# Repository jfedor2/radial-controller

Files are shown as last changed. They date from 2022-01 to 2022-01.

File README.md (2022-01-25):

# DIY Surface Dial

This repository contains 3D-printable design files and code that can be used to make a Surface Dial compatible USB radial controller.

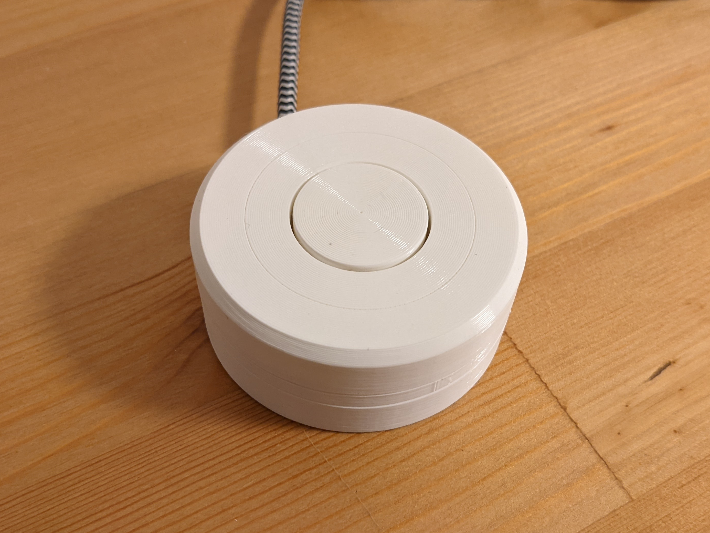
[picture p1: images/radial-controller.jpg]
Radial controller photo


The controller doesn't have all the features of the real Surface Dial. It's not wireless, it's not nearly as precise, it doesn't have haptic feedback and it doesn't have the on-screen positioning magic. But it should work in all applications compatible with the Surface Dial with no additional software.

It uses the following components:

* [Adafruit QT Py RP2040](https://www.adafruit.com/product/4900) (you can use any other board that will fit inside the case, but the code is for the RP2040)
* 2x [SS49E Hall effect sensors](https://sps.honeywell.com/us/en/products/sensing-and-iot/sensors/magnetic-sensors/linear-and-angle-sensor-ics/ss39et-ss49e-ss59et-linear-sensor-ics) (TO-92 package)
* 48x 2x2mm neodymium cylinder magnets (axially magnetized)
* Kailh low profile (choc v1) mechanical keyboard switch
* 30x42x7mm bearing (6806 ZZ)
* 2x M3x4 flat head screws
* a USB cable
* some hookup wire

The bearing and the magnets are press-fit into the case, but depending on your particular printer you might want to use glue. The Hall effect sensors should be oriented "face-up" and will definitely need some glue to stay in place.

The sensors' + and - leads are connected to 3.3V and GND, respectively, and their output leads are connected to pins A2 and A3. The keyboard switch is connected to pin A1 (the other contact to GND).

The magnets should be installed with alternating polarity (the outside-facing pole should be N-S-N-S... etc.).

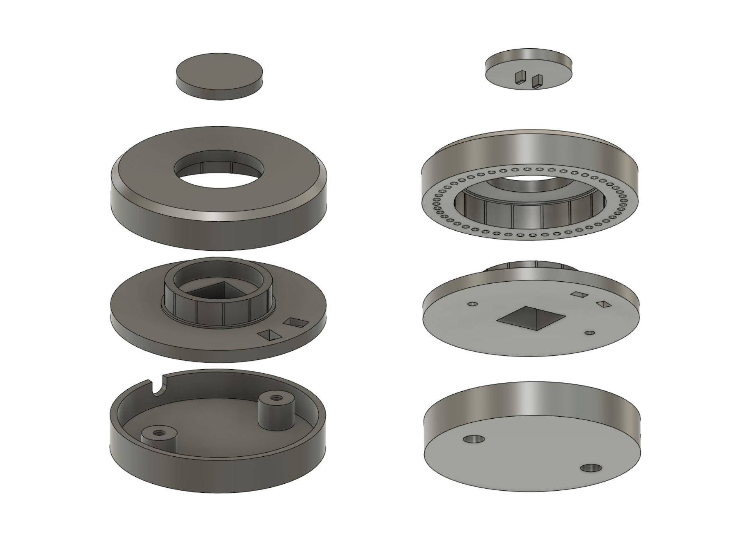
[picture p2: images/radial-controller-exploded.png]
Radial controller exploded view


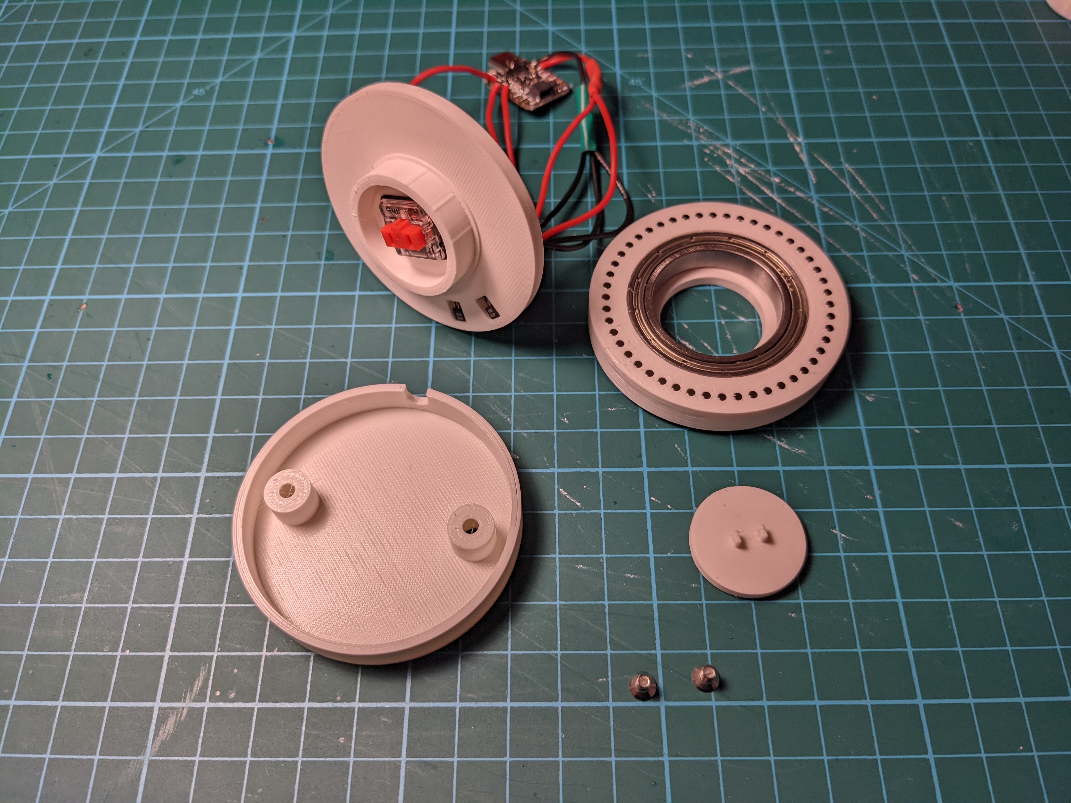
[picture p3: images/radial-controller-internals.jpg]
Radial controller internals


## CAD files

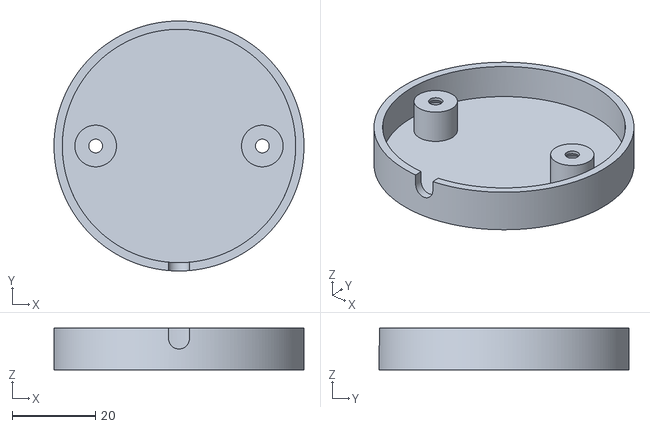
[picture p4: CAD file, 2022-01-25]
3d-models/RadialController-Bottom.stl
60.0 x 60.0 x 10.0

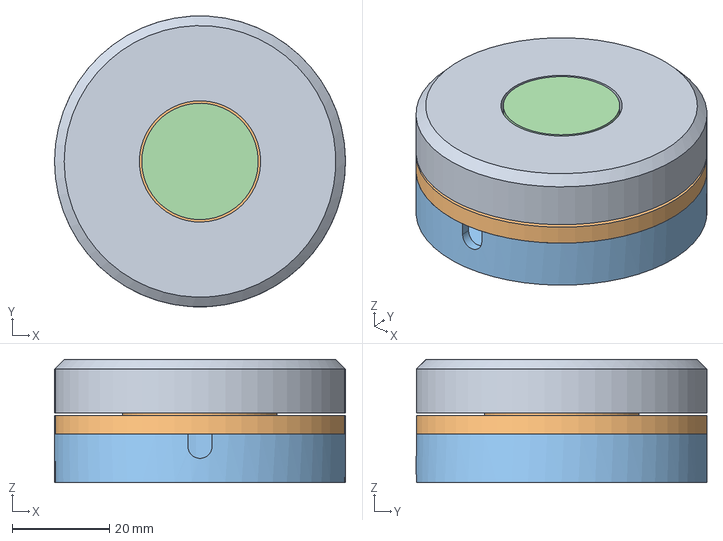
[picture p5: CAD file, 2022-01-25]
3d-models/RadialController.step
60.0 x 60.0 x 25.4 mm

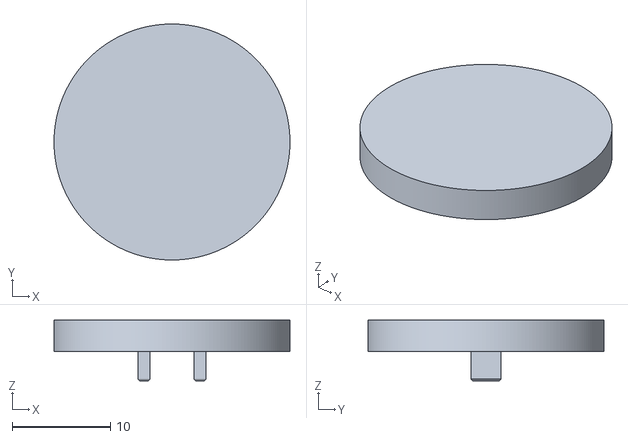
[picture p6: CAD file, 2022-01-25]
3d-models/RadialController-Button.stl
24.0 x 24.0 x 6.20

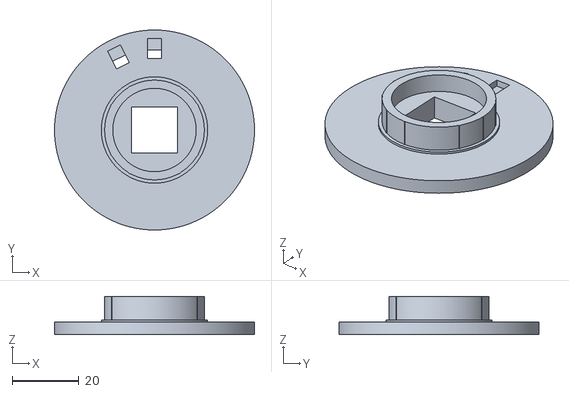
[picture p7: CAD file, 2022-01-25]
3d-models/RadialController-Mid.stl
60.0 x 60.0 x 11.4

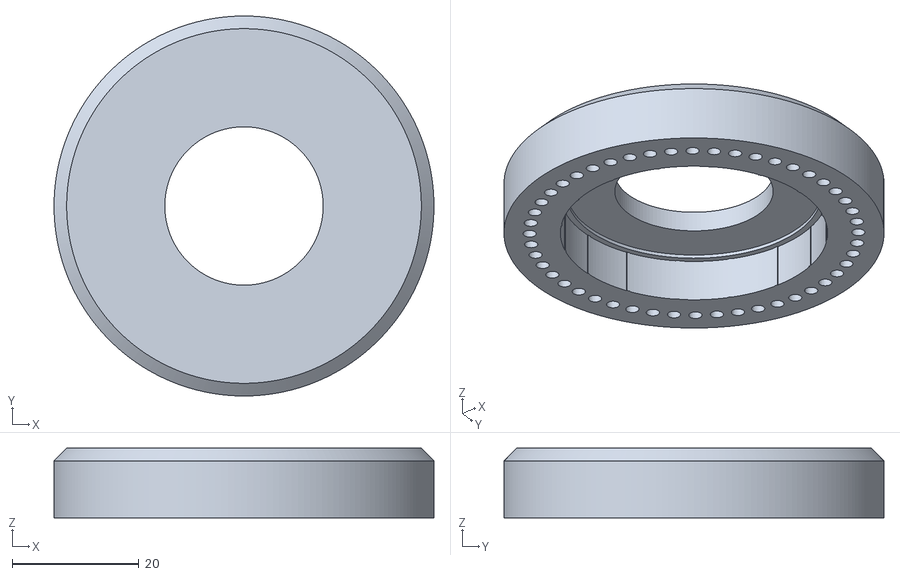
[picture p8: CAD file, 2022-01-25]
3d-models/RadialController-Top.stl
60.0 x 60.0 x 11.0

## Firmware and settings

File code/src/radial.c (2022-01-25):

/*
 * The MIT License (MIT)
 *
 * Copyright (c) 2022 Jacek Fedorynski
 * Copyright (c) 2019 Ha Thach (tinyusb.org)
 *
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
 */

#include <stdlib.h>
#include <stdio.h>
#include <string.h>
#include <math.h>

#include "bsp/board.h"
#include "tusb.h"

#include "pico/stdlib.h"
#include "pico/bootrom.h"

#include "hardware/gpio.h"
#include "hardware/adc.h"

#define BUTTON_PIN 28
#define SENSOR1_PIN 26
#define SENSOR2_PIN 27
#define SENSOR1_INPUT 0
#define SENSOR2_INPUT 1

#define DIAL_REPORT_ID 1
#define CLICKS_PER_360_DEGREES 48
#define UNITS_PER_CLICK (3600/CLICKS_PER_360_DEGREES)

// These IDs are bogus. If you want to distribute any hardware using this,
// you will have to get real ones.
#define USB_VID 0xCAFE
#define USB_PID 0xBAEA

tusb_desc_device_t const desc_device = {
    .bLength = sizeof(tusb_desc_device_t),
    .bDescriptorType = TUSB_DESC_DEVICE,
    .bcdUSB = 0x0200,
    .bDeviceClass = 0x00,
    .bDeviceSubClass = 0x00,
    .bDeviceProtocol = 0x00,
    .bMaxPacketSize0 = CFG_TUD_ENDPOINT0_SIZE,

    .idVendor = USB_VID,
    .idProduct = USB_PID,
    .bcdDevice = 0x0100,

    .iManufacturer = 0x01,
    .iProduct = 0x02,
    .iSerialNumber = 0x00,

    .bNumConfigurations = 0x01
};

// https://docs.microsoft.com/en-us/windows-hardware/design/component-guidelines/radial-controller-sample-report-descriptors
uint8_t const desc_hid_report[] = {
    0x05, 0x01,                 // USAGE_PAGE (Generic Desktop)
    0x09, 0x0e,                 // USAGE (System Multi-Axis Controller)
    0xa1, 0x01,                 // COLLECTION (Application)
    0x85, DIAL_REPORT_ID,       //   REPORT_ID (Radial Controller)
    0x05, 0x0d,                 //   USAGE_PAGE (Digitizers)
    0x09, 0x21,                 //   USAGE (Puck)
    0xa1, 0x00,                 //   COLLECTION (Physical)
    0x05, 0x09,                 //     USAGE_PAGE (Buttons)
    0x09, 0x01,                 //     USAGE (Button 1)
    0x95, 0x01,                 //     REPORT_COUNT (1)
    0x75, 0x01,                 //     REPORT_SIZE (1)
    0x15, 0x00,                 //     LOGICAL_MINIMUM (0)
    0x25, 0x01,                 //     LOGICAL_MAXIMUM (1)
    0x81, 0x02,                 //     INPUT (Data,Var,Abs)
    0x05, 0x01,                 //     USAGE_PAGE (Generic Desktop)
    0x09, 0x37,                 //     USAGE (Dial)
    0x95, 0x01,                 //     REPORT_COUNT (1)
    0x75, 0x0f,                 //     REPORT_SIZE (15)
    0x55, 0x0f,                 //     UNIT_EXPONENT (-1)
    0x65, 0x14,                 //     UNIT (Degrees, English Rotation)
    0x36, 0xf0, 0xf1,           //     PHYSICAL_MINIMUM (-3600)
    0x46, 0x10, 0x0e,           //     PHYSICAL_MAXIMUM (3600)
    0x16, 0xf0, 0xf1,           //     LOGICAL_MINIMUM (-3600)
    0x26, 0x10, 0x0e,           //     LOGICAL_MAXIMUM (3600)
    0x81, 0x06,                 //     INPUT (Data,Var,Rel)
    0xc0,                       //   END_COLLECTION
    0xc0,                       // END_COLLECTION
};

#define CONFIG_TOTAL_LEN (TUD_CONFIG_DESC_LEN + TUD_HID_DESC_LEN)
#define EPNUM_HID 0x81

uint8_t const desc_configuration[] = {
    // Config number, interface count, string index, total length, attribute, power in mA
    TUD_CONFIG_DESCRIPTOR(1, 1, 0, CONFIG_TOTAL_LEN, 0, 100),

    // Interface number, string index, protocol, report descriptor len, EP In address, size & polling interval
    TUD_HID_DESCRIPTOR(0, 0, HID_ITF_PROTOCOL_NONE, sizeof(desc_hid_report), EPNUM_HID, CFG_TUD_HID_EP_BUFSIZE, 1)
};

char const *string_desc_arr[] = {
    (const char[]) {0x09, 0x04},        // 0: is supported language is English (0x0409)
    "Arasaka",                  // 1: Manufacturer
    "Radial Controller",        // 2: Product
};

// HID report
typedef struct __attribute__ ((packed)) {
    uint16_t button:1;
    int16_t rotation:15;
} hid_report_t;

hid_report_t report;

int encoder_rotation = 0;
int prev_state1 = 0;

void encoder_task(void) {
    adc_select_input(SENSOR1_INPUT);
    uint16_t val1 = adc_read();
    adc_select_input(SENSOR2_INPUT);
    uint16_t val2 = adc_read();

    int state1 = prev_state1;
    if (val1 > 2670) {
        state1 = 1;
    }
    if (val1 < 1602) {
        state1 = -1;
    }

    int state2 = 0;
    if (val2 > 2048) {
        state2 = 1;
    }
    if (val2 < 2048) {
        state2 = -1;
    }

    if (prev_state1 != state1) {
        if (state1 == state2) {
            encoder_rotation -= UNITS_PER_CLICK;
        }
        if (state1 == -state2) {
            encoder_rotation += UNITS_PER_CLICK;
        }
    }

    prev_state1 = state1;
}

inline float away_from_zero(float x) {
    if (x > 0) {
        return ceilf(x);
    }
    if (x < 0) {
        return floorf(x);
    }
    return x;
}

void hid_task(void) {
    if (!tud_hid_ready()) {
        return;
    }

    report.button = !gpio_get(BUTTON_PIN);

    // Scroll doesn't work very well if we send 7.5 degrees of rotation
    // in one report. So we spread small chunks over several reports, which
    // makes the software happy. It adds some delay, but it's negligible
    // in practice. It wouldn't be necessary if we had a high-resolution
    // rotary encoder.
    report.rotation = away_from_zero(5.0f * encoder_rotation / UNITS_PER_CLICK);
    encoder_rotation -= report.rotation;

    tud_hid_report(DIAL_REPORT_ID, &report, sizeof(report));
}

void pins_init(void) {
    adc_init();
    adc_gpio_init(SENSOR1_PIN);
    adc_gpio_init(SENSOR2_PIN);
    gpio_init(BUTTON_PIN);
    gpio_set_dir(BUTTON_PIN, GPIO_IN);
    gpio_pull_up(BUTTON_PIN);

    // reset into BOOTSEL if button pressed while plugging in
    // (convenient during development)
    sleep_ms(50);
    if (!gpio_get(BUTTON_PIN)) {
        reset_usb_boot(0, 0);
    }
}

void report_init(void) {
    memset(&report, 0, sizeof(report));
}

int main(void) {
    stdio_init_all();
    board_init();
    pins_init();
    report_init();
    tusb_init();

    while (1) {
        tud_task();             // tinyusb device task
        encoder_task();
        hid_task();
    }

    return 0;
}

// Invoked when received GET DEVICE DESCRIPTOR
// Application return pointer to descriptor
uint8_t const *tud_descriptor_device_cb(void) {
    return (uint8_t const *) &desc_device;
}

// Invoked when received GET HID REPORT DESCRIPTOR
// Application return pointer to descriptor
// Descriptor contents must exist long enough for transfer to complete
uint8_t const *tud_hid_descriptor_report_cb(uint8_t itf) {
    return desc_hid_report;
}

// Invoked when received GET_REPORT control request
// Application must fill buffer report's content and return its length.
// Return zero will cause the stack to STALL request
uint16_t tud_hid_get_report_cb(uint8_t itf, uint8_t report_id, hid_report_type_t report_type, uint8_t * buffer, uint16_t reqlen) {
    return 0;
}

// Invoked when received SET_REPORT control request or
// received data on OUT endpoint ( Report ID = 0, Type = 0 )
void tud_hid_set_report_cb(uint8_t itf, uint8_t report_id, hid_report_type_t report_type, uint8_t const *buffer, uint16_t bufsize) {
}

// Invoked when received GET CONFIGURATION DESCRIPTOR
// Application return pointer to descriptor
// Descriptor contents must exist long enough for transfer to complete
uint8_t const *tud_descriptor_configuration_cb(uint8_t index) {
    return desc_configuration;
}

static uint16_t _desc_str[32];

// Invoked when received GET STRING DESCRIPTOR request
// Application return pointer to descriptor, whose contents must exist long enough for transfer to complete
uint16_t const *tud_descriptor_string_cb(uint8_t index, uint16_t langid) {
    uint8_t chr_count;

    if (index == 0) {
        memcpy(&_desc_str[1], string_desc_arr[0], 2);
        chr_count = 1;
    } else {
        // Note: the 0xEE index string is a Microsoft OS 1.0 Descriptors.
        // https://docs.microsoft.com/en-us/windows-hardware/drivers/usbcon/microsoft-defined-usb-descriptors

        if (!(index < sizeof(string_desc_arr) / sizeof(string_desc_arr[0])))
            return NULL;

        const char *str = string_desc_arr[index];

        // Cap at max char
        chr_count = strlen(str);
        if (chr_count > 31)
            chr_count = 31;

        // Convert ASCII string into UTF-16
        for (uint8_t i = 0; i < chr_count; i++) {
            _desc_str[1 + i] = str[i];
        }
    }

    // first byte is length (including header), second byte is string type
    _desc_str[0] = (TUSB_DESC_STRING << 8) | (2 * chr_count + 2);

    return _desc_str;
}
